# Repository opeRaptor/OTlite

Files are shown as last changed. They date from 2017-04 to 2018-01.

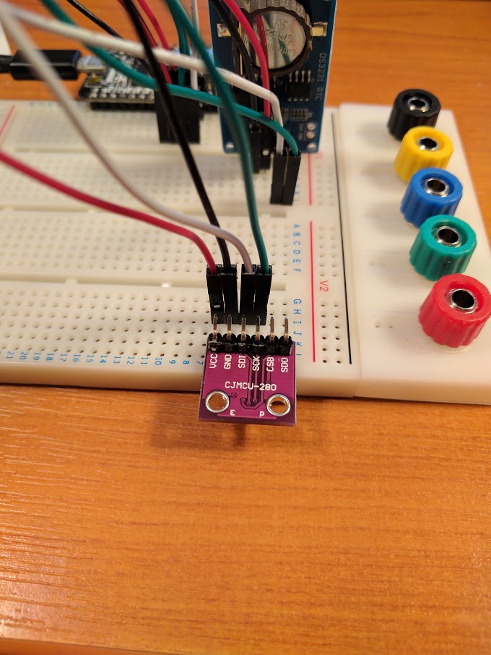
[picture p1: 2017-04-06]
Software/IMG_20170405_214116.jpg

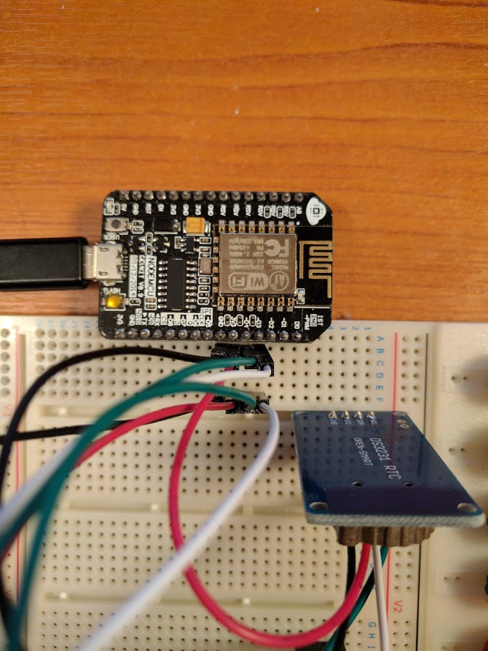
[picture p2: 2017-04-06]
Software/IMG_20170405_214140.jpg

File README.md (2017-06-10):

Obsolete Time Lite or O;TL for short, is the natural evolution of a previous project aiming to design the perfect desktop Nixie clock. 

 -Minimal design
 
 -Small form factor 
 
 -WiFi capable 
 
 -USB power 
 
 -Various atmospheric sensors. 

Reach out on Twitter: 
@SuprNova

Follow development on HackaDay.io:
https://hackaday.io/project/20439-obsolete-time-lite-a-minty-nixie-clock

OTL

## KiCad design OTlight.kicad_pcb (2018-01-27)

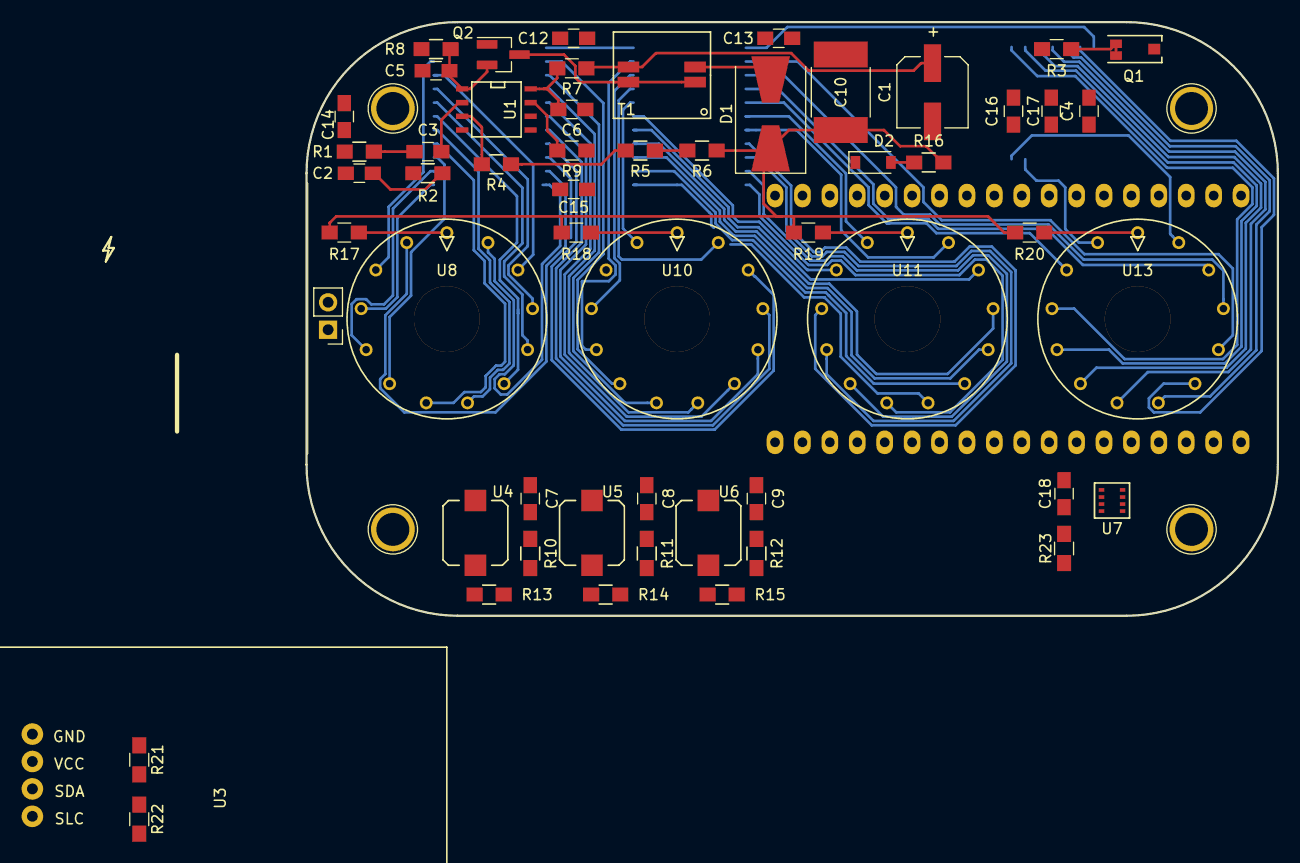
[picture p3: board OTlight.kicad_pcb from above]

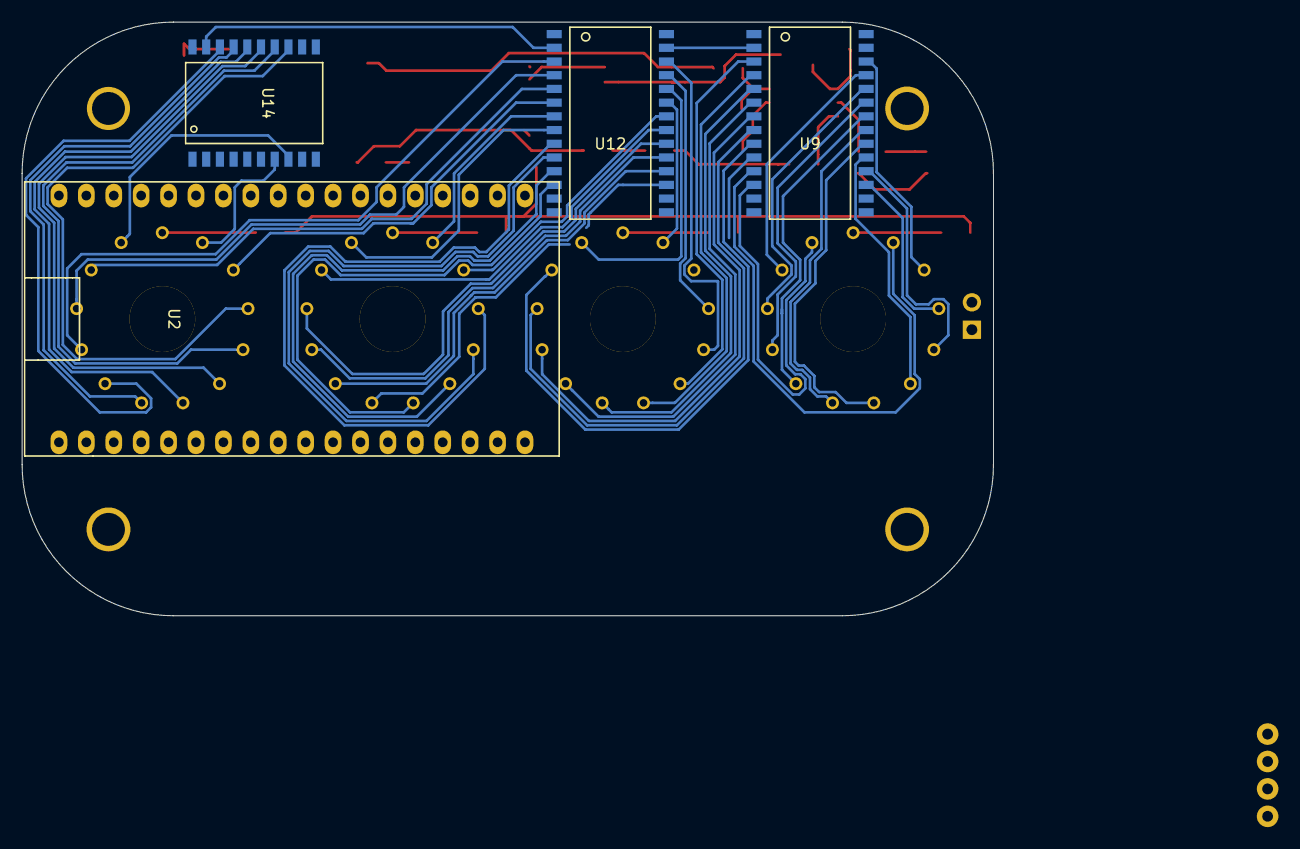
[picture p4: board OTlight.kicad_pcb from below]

Board: 2 copper layers, 90.0 x 55.0 mm, 60 parts (4 on the bottom side), 82 nets.

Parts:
C1: 220u; CP_Elec_6.3x7.7
C2: 0.001; C_0805_HandSoldering
C3, C6, C7, C8, C9, C18: 0.1u; C_0805_HandSoldering
C4: 10u; C_0805_HandSoldering
C5: 0.01u; C_0805_HandSoldering
C10: 1u; C_2220_HandSoldering
C12, C13, C14, C15, C16, C17: C_Small; C_0805_HandSoldering
D1: STPS4S200; D_SMB-SMC_Universal_Handsoldering
D2: D_Zener_Small_ALT; D_SOD-123
P1: CONN_01X02; Pin_Header_Straight_1x02_Pitch2.54mm
Q1: TEMT6000
Q2: RSR030N06TL; SOT-23_Handsoldering
R1: 1K; R_0805_HandSoldering
R2: 13K; R_0805_HandSoldering
R3, R10, R11, R12, R13, R14, R15, R16, R17, R18, R19, R20, R21, R22, R23: R_Small; R_0805_HandSoldering
R4: 1M; R_0805_HandSoldering
R5: 820K; R_0805_HandSoldering
R6: 24K; R_0805_HandSoldering
R7: 20; R_0805_HandSoldering
R8: 0.1; R_0805_HandSoldering
R9: 15K; R_0805_HandSoldering
T1: TRANSFO; CTX02-18714-R
U1: LM3478; SOIC-8-N
U2: ESP32; ESP32-OLED
U3: DS3231
U4, U5, U6: PushButton; SPEH120100
U7: bareBME280; BME280bare
U8, U10, U11, U13: IN-14; bearing-7mm
U9, U12: MAX6931; SW-28
U14: MAX6920; SW-20

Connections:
+3V3: C14.1, C15.1, C16.1, C18.2, Q1.1, R21.1, R22.1, R23.2, U3.2, U4.2, U5.2, U6.2, U7.2, U7.6, U7.8, U9.28, U12.28, U14.20
+5V: C1.1, C4.1, R7.1, T1.3
/CLK: U9.15, U12.15, U14.11
/HVout: C10.1, D1.1, P1.1, R6.1, R16.1, R17.1, R18.1, R19.1, R20.1
/LOAD: U9.16, U12.16, U14.12
GND: C1.2, C2.2, C4.2, C5.2, C6.2, C7.2, C8.2, C9.2, C10.2, C12.1, C13.1, C14.2, C15.2, C16.2, C17.1, C18.1, D2.1, P1.2, R1.2, R2.2, R3.2, R8.2, R9.1, R13.2, R14.2, R15.2, U1.4, U1.5, U3.1, U7.1, U7.7, U9.13, U9.14, U12.13, U12.14, U14.9, U14.10
unnamed: C2.1, R2.1, R4.2, U1.3
unnamed: C3.1, U1.2
unnamed: C3.2, R1.1
unnamed: C5.1, Q2.2, R8.1, U1.1
unnamed: C6.1, R7.2, U1.8
unnamed: C7.1, R10.1
unnamed: C8.1, R11.1
unnamed: C9.1, R12.1
unnamed: C12.2, C13.2, C17.2, D2.2, R16.2, U9.1, U12.1, U14.1
unnamed: D1.2, T1.2
unnamed: Q1.2, R3.1
unnamed: Q2.1, U1.6
unnamed: Q2.3, T1.1, T1.4
unnamed: R4.1, R5.2
unnamed: R5.1, R6.2
unnamed: R9.2, U1.7
unnamed: R10.2, R13.1, U4.1
unnamed: R11.2, R14.1, U5.1
unnamed: R12.2, R15.1, U6.1
unnamed: R17.2, U8.1
unnamed: R18.2, U10.1
unnamed: R19.2, U11.1
unnamed: R20.2, U13.1
unnamed: R21.2, U3.3, U7.3
unnamed: R22.2, U3.4, U7.4
unnamed: R23.1, U7.5
unnamed: U8.2, U9.12
unnamed: U8.3, U9.25
unnamed: U8.4, U9.24
unnamed: U8.5, U9.23
unnamed: U8.6, U9.22
unnamed: U8.7, U9.21
unnamed: U8.8, U9.20
unnamed: U8.9, U9.19
unnamed: U8.10, U9.18
unnamed: U8.11, U9.17
unnamed: U8.12, U9.26
unnamed: U8.13, U9.11
unnamed: U10.2, U12.24
unnamed: U9.9, U10.3
unnamed: U9.8, U10.4
unnamed: U9.7, U10.5
unnamed: U9.6, U10.6
unnamed: U9.5, U10.7
unnamed: U9.4, U10.8
unnamed: U9.3, U10.9
unnamed: U10.10, U12.26
unnamed: U10.11, U12.25
unnamed: U9.10, U10.12
unnamed: U10.13, U12.23
unnamed: U11.2, U12.8
unnamed: U11.3, U12.21
unnamed: U11.4, U12.20
unnamed: U11.5, U12.19
unnamed: U11.6, U12.18
unnamed: U11.7, U12.17
unnamed: U11.8, U12.12
unnamed: U11.9, U12.11
unnamed: U11.10, U12.10
unnamed: U11.11, U12.9
unnamed: U11.12, U12.22
unnamed: U11.13, U12.7
unnamed: U12.2, U14.19
unnamed: U12.3, U13.5
unnamed: U12.4, U13.4
unnamed: U12.5, U13.3
unnamed: U12.6, U13.12
unnamed: U9.2, U12.27
unnamed: U13.2, U14.8
unnamed: U13.6, U14.18
unnamed: U13.7, U14.17
unnamed: U13.8, U14.16
unnamed: U13.9, U14.15
unnamed: U13.10, U14.14
unnamed: U13.11, U14.13
unnamed: U13.13, U14.7

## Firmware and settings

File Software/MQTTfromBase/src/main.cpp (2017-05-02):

#include "Arduino.h"
#include <ESP8266WiFi.h>
#include <Wire.h>
#include <SPI.h>
#include "RTClib.h"
#include <PubSubClient.h>
#include <WiFiUdp.h>

RTC_DS3231 rtc;
char daysOfTheWeek[7][12] = {"Sunday", "Monday", "Tuesday", "Wednesday", "Thursday", "Friday", "Saturday"};

#define BME_SCK 13
#define BME_MISO 12
#define BME_MOSI 11
#define BME_CS 10
#define left_Button 16
#define middle_Button 5
#define right_Button 4



void shift(int NixietodisplayUpdate [8]);
void shift(int NixietodisplayUpdate);
void displayUpdate (int duration);
void displayUpdate (void);
void displayUpdate (int numbers,int duration);
void GetTime();
void GetDate();

void callback(char* topic, byte* payload, unsigned int length);
void reconnect();

bool adjust(void); //NTP time adjust
void sendNTPpacket(IPAddress *address);

unsigned long delayTime;

//=======================================INCLUDE==NTP======================================
/// NTP Server address
const char* ntpServerName = "0.uk.pool.ntp.org";
const double timezone = 1.0;
// local port to listen for UDP packets
const unsigned int localPort = 2390;
/// A UDP instance to let us send and receive packets over UDP
WiFiUDP udp;

/// Weekday strings.
//char daysOfTheWeek[][4] = {"Sun", "Mon", "Tue", "Wed", "Thu", "Fri", "Sat"};
/**
 * @brief NTP Server IP variable.
 *
 * Don't hardwire the IP address or we won't get the benefits of the pool.
 */
IPAddress timeServerIP;
/// NTP time stamp is in the first 48 bytes of the message
const int NTP_PACKET_SIZE = 48;
/// buffer to hold incoming and outgoing packets
byte packetBuffer[ NTP_PACKET_SIZE];
//===================================================================================

int NixieArray [8];
int PreviousArray [8];
int Brightness = 10;
int transition = 16;

int clockPin = 13;
int BL = 15;
int dataPin = 14;
int latch = 12;


const char* mqtt_server = "iot.eclipse.org";
WiFiClient espClient;
PubSubClient client(espClient);
long lastMsg = 0;
char msg[50];
int value = 0;

void setup() {

  Serial.begin(9600);
  Wire.pins(0, 2); //SDA and SCL

  //MQTT setup
  client.setServer(mqtt_server, 1883);
  client.setCallback(callback);

  if (! rtc.begin()) {
    Serial.println("Couldn't find RTC");
    while (1);
  }

  if (rtc.lostPower()) {
    Serial.println("RTC lost power, lets set the time!");
    rtc.adjust(DateTime(F(__DATE__), F(__TIME__)));
  }

  // Start UDP Server to receive the NTP response.
  Serial.println("Starting UDP");
  udp.begin(localPort);
  Serial.println("Initial RTC sync with NTP");
  while (!adjust()){
    adjust();
  }

  pinMode(clockPin, OUTPUT);
  pinMode(BL, OUTPUT);
  pinMode(dataPin, OUTPUT);
  pinMode(latch, OUTPUT);

  pinMode(16, INPUT); // Left button
  pinMode(5, INPUT);  // Middle button
  pinMode(4, INPUT);  // Right button

  digitalWrite(BL, LOW);
  digitalWrite(latch, HIGH);

  digitalWrite(dataPin, HIGH);
  for (int i = 0; i < 50; i++)
  {
    digitalWrite(clockPin, HIGH);
    digitalWrite(clockPin, LOW);
  }

  if (!client.connected()) {
    reconnect();
  }

}


void loop()
{
  GetTime();
  displayUpdate();

  client.loop();

  DateTime now = rtc.now();
  int nowish = now.minute() / 10;

  if (nowish != lastMsg) {
    lastMsg = now.minute() / 10;
    ++value;
    snprintf (msg, 75, "x10min: %ld", value);
    //Serial.print("Publish message: ");
    //Serial.println(msg);
    client.publish("/OTL/batt", msg);
  }

  /*if (digitalRead(left_Button) == 1)
  {
    //see bottom of program for draft of chrono
  }

  if (digitalRead(middle_Button) == 1)
  {
    GetDate();
    displayUpdate (14);
    while (digitalRead(middle_Button) == 1)
    {
      displayUpdate(14);
    }
    GetTime();
    displayUpdate (14);
  }
  if (digitalRead(right_Button) == 1)
  {

    displayUpdate (14);
    while (digitalRead(middle_Button) == 1)
    {
      displayUpdate(14);
    }
    GetTime();
    displayUpdate (14);
  }*/
}

//=======================================FUNCTION==DISPLAYUPDATE================================
// Do a smooth transition between the previous array dipslayed and NiexieArray, for a given duration
void displayUpdate (int duration)
{
  int dots [8] = {10, 10, 10, 10, 0, 0, 0, 0};
  for (int i = 0; i < 4; ++i)
  {
    if ((PreviousArray [i]) != (NixieArray [i])) goto Change;
  }
  dots [4] = NixieArray [4];
  dots [5] = NixieArray [5];
  dots [6] = NixieArray [6];
  dots [7] = NixieArray [7];

  shift (NixieArray);
  delayMicroseconds (Brightness * 300);

  shift (dots);
  delayMicroseconds (Brightness * 50);

  if (Brightness != 10)
  {
    shift (10000);
    delayMicroseconds (3000 - Brightness * 300);
  }

  for (int i = 0; i < 8; ++i)
  {
    PreviousArray [i] = NixieArray [i];
  }
  return;

Change:
  dots [4] = NixieArray [4];
  dots [5] = NixieArray [5];
  dots [6] = NixieArray [6];
  dots [7] = NixieArray [7];

  int dots2 [8] = {10, 10, 10, 10, 0, 0, 0, 0};
  dots2 [4] = PreviousArray [4];
  dots2 [5] = PreviousArray [5];
  dots2 [6] = PreviousArray [6];
  dots2 [7] = PreviousArray [7];

  for (int i = 0; i < duration; i++)
  {
    shift (PreviousArray);
    delayMicroseconds ((duration - i) * 1000 * Brightness / 10);
    shift (dots2);
    delayMicroseconds ((duration - i) * 1000 * Brightness / 60);
    if (Brightness != 10)
    {
    shift (10000);
    delayMicroseconds ((duration - i) * 1000 * (10 - Brightness) / 10);
    }

    shift (NixieArray);
    delayMicroseconds (i * 1000 * Brightness / 10);
    shift (dots);
    delayMicroseconds (i * 1000 * Brightness / 60);
    if (Brightness != 10)
    {
    shift (10000);
    delayMicroseconds (i * 1000 * (10 - Brightness) / 10);
    }
  }
  for (int i = 0; i < 8; ++i)
  {
    PreviousArray [i] = NixieArray [i];
  }
}

void displayUpdate (void)
{
  displayUpdate(transition);
}

void displayUpdate (int numbers, int duration)
{
  NixieArray [0] = numbers / 1000;
  NixieArray [1] = (numbers / 100) % 10;
  NixieArray [2] = (numbers / 10) % 10;
  NixieArray [3] = numbers % 10;
  displayUpdate (duration);
}

//=======================================FUNCTION==SHIFT==============================
// displayUpdate numbers and dots, from an int array, left to right, 4 first are numbers, 4 last are dots
// If a number is not in the range 0-9, no numbers are lit up
// Dots: 0 is nothing, 1 is left dot, 2 is right dot, 3 is both dots
void shift(int NixietodisplayUpdate [8])
{
  int Nixiearray [10] = {8, 9, 0, 1, 2, 3, 4, 5, 6, 7};
  int j;

  for (int k = 3; k >= 0; k--)
  {
    digitalWrite(latch, LOW);
    digitalWrite(dataPin, HIGH);

    if ((NixietodisplayUpdate [k + 4] == 3) || (NixietodisplayUpdate [k + 4] == 1))   digitalWrite(dataPin, LOW);
    digitalWrite(clockPin, HIGH);
    digitalWrite(clockPin, LOW);
    digitalWrite(dataPin, HIGH);

    if ((NixietodisplayUpdate [k + 4] == 3) || (NixietodisplayUpdate [k + 4] == 2))   digitalWrite(dataPin, LOW);
    digitalWrite(clockPin, HIGH);
    digitalWrite(clockPin, LOW);
    digitalWrite(dataPin, HIGH);

    if ((NixietodisplayUpdate [k] > 9) || (NixietodisplayUpdate [k] < 0))
    {
      for (int i = 0; i < 10; i++)
      {
        digitalWrite(clockPin, HIGH);
        digitalWrite(clockPin, LOW);
      }
    }
    else
    {
      j = Nixiearray [NixietodisplayUpdate [k]];
      for (int i = 0; i < j; i++)
      {
        digitalWrite(clockPin, HIGH);
        digitalWrite(clockPin, LOW);
      }
      digitalWrite(dataPin, LOW);
      digitalWrite(clockPin, HIGH);
      digitalWrite(clockPin, LOW);
      digitalWrite(dataPin, HIGH);
      for (int i = 0; i < (9 - j); i++)
      {
        digitalWrite(clockPin, HIGH);
        digitalWrite(clockPin, LOW);
      }
    }
    digitalWrite(latch, HIGH);
  }
}

void shift(int NixietodisplayUpdate)
{
  int nixiebuffer [8];
  if (NixietodisplayUpdate == 10000)
  {
    nixiebuffer [0] = 10;
    nixiebuffer [1] = 10;
    nixiebuffer [2] = 10;
    nixiebuffer [3] = 10;
  }
  else
  {
    nixiebuffer [0] = NixietodisplayUpdate / 1000;
    nixiebuffer [1] = (NixietodisplayUpdate / 100) % 10;
    nixiebuffer [2] = (NixietodisplayUpdate / 10) % 10;
    nixiebuffer [3] = NixietodisplayUpdate % 10;
  }
  nixiebuffer [4] = 0;
  nixiebuffer [5] = 0;
  nixiebuffer [6] = 0;
  nixiebuffer [7] = 0;
  if (NixietodisplayUpdate == 10000)
  {
    nixiebuffer [0] = 10;
    nixiebuffer [1] = 10;
    nixiebuffer [2] = 10;
    nixiebuffer [3] = 10;
  }

  shift(nixiebuffer);
}

//=======================================FUNCTION==GETTIME================================
void GetTime()
{
  DateTime now = rtc.now();

  NixieArray [0] = now.hour() / 10;
  NixieArray [1] = now.hour() % 10;
  NixieArray [2] = now.minute() / 10;
  NixieArray [3] = now.minute() % 10;
  NixieArray [4] = 0;
  NixieArray [5] = 0;
  NixieArray [6] = 0;
  NixieArray [7] = 0;

  if ((now.second() % 2) == 1) NixieArray [5] = 2;
  else NixieArray [6] = 1;
}


//=======================================FUNCTION==GETDATE================================
void GetDate()
{
  DateTime now = rtc.now();

  NixieArray [0] = now.month() / 10;
  NixieArray [1] = now.month() % 10;
  NixieArray [2] = now.day() / 10;
  NixieArray [3] = now.day() % 10;
  NixieArray [4] = 0;
  NixieArray [5] = 2;
  NixieArray [6] = 0;
  NixieArray [7] = 0;
}

//=======================================FUNCTION==SERIAL==RTC============================
void printRTCValues() {
  DateTime now = rtc.now();

  Serial.print(now.year(), DEC);
  Serial.print('/');
  Serial.print(now.month(), DEC);
  Serial.print('/');
  Serial.print(now.day(), DEC);
  Serial.print(" (");
  Serial.print(daysOfTheWeek[now.dayOfTheWeek()]);
  Serial.print(") ");
  Serial.print(now.hour(), DEC);
  Serial.print(':');
  Serial.print(now.minute(), DEC);
  Serial.print(':');
  Serial.print(now.second(), DEC);
  Serial.println();

  Serial.println();
  delay(delayTime);
}
//=======================================FUNCTION==MQTTCallback============================
void callback(char* topic, byte* payload, unsigned int length) {
  Serial.print("Message arrived [");
  Serial.print(topic);
  Serial.print("] ");
  for (int i = 0; i < length; i++) {
    Serial.print((char)payload[i]);
  }
  Serial.println();
}
//=======================================FUNCTION==MQTTreconnect============================
void reconnect() {
  // Loop until we're reconnected
  while (!client.connected()) {
    Serial.print("Attempting MQTT connection...");
    // Create a random client ID
    String clientId = "ESP8266Client-";
    clientId += String(random(0xffff), HEX);
    // Attempt to connect
    if (client.connect(clientId.c_str())) {
      Serial.println("connected");
      // Once connected, publish an announcement...
      client.publish("/OTL/batt", "beginBatt test");
      // ... and resubscribe
      client.subscribe("/OTL/incoming");
    } else {
      Serial.print("failed, rc=");
      Serial.print(client.state());
      Serial.println(" try again in 5 seconds");
      // Wait 5 seconds before retrying
      delay(5000);
    }
  }
}
//=======================================NTP==FUNCTION============================================
/**
 * @brief Adjust the DS3231 with current date and time.
 *
 * <pre>
 * NTPv4 Basic Header Specification:
 *
 * Bytes  : Description
 * -------:----------------------
 *       0: LI(2), VN(3), Mode(3)
 *       1: Stratum
 *       2: Poll
 *       3: Precision
 *  4 -  7: Root Delay
 *  8 - 11: Root Dispersion
 * 12 - 15: Reference ID
 * 16 - 23: Reference Timestamp
 * 24 - 31: Origin Timestamp
 * 32 - 39: Receive Timestamp
 * 40 - 47: Transmit Timestamp
 *
 * Transmit Timestamp:
 * Time at the server when the response left for the client, in NTP timestamp format.
 *
 *
 * NTP timestamp format
 *
 * Bytes: Description
 * -----:-------------------
 * 0 - 3: Seconds since 1900
 * 4 - 7: Fraction of Second
 * </pre>
 *
 */
bool adjust(void)
{
  unsigned long mi;
  int cb = 0;

  //get a random server from the pool
  WiFi.hostByName(ntpServerName, timeServerIP);

  // send an NTP packet to a time server
  sendNTPpacket(&timeServerIP);
  mi = millis();

  // wait to see if a reply is available
  while (millis() - mi < 2000 && !cb)
  {
    cb = udp.parsePacket();
    yield();
  }

  if (!cb)
  {
    Serial.println("[ERROR]: No packet available.");

    return 0;
  }

  //Serial.print("packet received, length=");
  //Serial.println(cb);
  // We've received a packet, read the data from it
  udp.read(packetBuffer, NTP_PACKET_SIZE); // read the packet into the buffer

  //the timestamp starts at byte 40 of the received packet and is four bytes,
  // or two words, long. First, esxtract the two words:

  unsigned long highWord = word(packetBuffer[40], packetBuffer[41]);
  unsigned long lowWord = word(packetBuffer[42], packetBuffer[43]);
  // combine the four bytes (two words) into a long integer
  // this is NTP time (seconds since Jan 1 1900):
  unsigned long secsSince1900 = highWord << 16 | lowWord;
  //Serial.print("Seconds since Jan 1 1900 = " );
  //Serial.println(secsSince1900);

  // now convert NTP time into everyday time:
  Serial.print("Unix UTC time = ");
  // Unix time starts on Jan 1 1970. In seconds, that's 2208988800:
  const unsigned long seventyYears = 2208988800UL;
  // subtract seventy years:
  unsigned long epoch = secsSince1900 - seventyYears;
  // print Unix time:
  Serial.println(epoch);

  // adjust to user timezone
  epoch += timezone * 3600;

  //rtc.setEpoch(epoch);
  rtc.adjust(epoch); //adjust RTC time to NTP time
  return 1;
}

void sendNTPpacket(IPAddress *address)
{
  Serial.println("sending NTP packet...");

  // set all bytes in the buffer to 0
  memset(packetBuffer, 0, NTP_PACKET_SIZE);

  // Initialize values needed to form NTP request
  // (see URL above for details on the packets)
  packetBuffer[0] = 0b11100011;   // LI, Version, Mode
  packetBuffer[1] = 0;     // Stratum, or type of clock
  packetBuffer[2] = 6;     // Polling Interval
  packetBuffer[3] = 0xEC;  // Peer Clock Precision
  // 8 bytes of zero for Root Delay & Root Dispersion
  packetBuffer[12]  = 49;
  packetBuffer[13]  = 0x4E;
  packetBuffer[14]  = 49;
  packetBuffer[15]  = 52;

  // all NTP fields have been given values, now
  // you can send a packet requesting a timestamp:
  udp.beginPacket(*address, 123); //NTP requests are to port 123
  udp.write(packetBuffer, NTP_PACKET_SIZE);
  udp.endPacket();
}

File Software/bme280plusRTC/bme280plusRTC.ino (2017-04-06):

/***************************************************************************
  This is a library for the BME280 humidity, temperature & pressure sensor

  Designed specifically to work with the Adafruit BME280 Breakout
  ----> http://www.adafruit.com/products/2650

  These sensors use I2C or SPI to communicate, 2 or 4 pins are required
  to interface. The device's I2C address is either 0x76 or 0x77.

  Adafruit invests time and resources providing this open source code,
  please support Adafruit andopen-source hardware by purchasing products
  from Adafruit!

  Written by Limor Fried & Kevin Townsend for Adafruit Industries.
  BSD license, all text above must be included in any redistribution
 ***************************************************************************/

#include <Wire.h>
#include <SPI.h>
#include <Adafruit_Sensor.h>
#include <Adafruit_BME280.h>
#include "RTClib.h"

RTC_DS3231 rtc;
char daysOfTheWeek[7][12] = {"Sunday", "Monday", "Tuesday", "Wednesday", "Thursday", "Friday", "Saturday"};

#define BME_SCK 13
#define BME_MISO 12
#define BME_MOSI 11
#define BME_CS 10

#define SEALEVELPRESSURE_HPA (1013.25)

Adafruit_BME280 bme; // I2C
//Adafruit_BME280 bme(BME_CS); // hardware SPI
//Adafruit_BME280 bme(BME_CS, BME_MOSI, BME_MISO, BME_SCK); // software SPI

unsigned long delayTime;

void setup() {
    
    Serial.begin(9600);
    Wire.pins(0,2); //SDA and SCL
    Serial.println(F("BME280 test"));

    if (! rtc.begin()) {
    Serial.println("Couldn't find RTC");
    while (1);
  }

  if (rtc.lostPower()) {
    Serial.println("RTC lost power, lets set the time!");
    // following line sets the RTC to the date & time this sketch was compiled
    rtc.adjust(DateTime(F(__DATE__), F(__TIME__)));
    // This line sets the RTC with an explicit date & time, for example to set
    // January 21, 2014 at 3am you would call:
    // rtc.adjust(DateTime(2014, 1, 21, 3, 0, 0));
  }


    bool status;
    
    // default settings
    status = bme.begin();
    if (!status) {
        Serial.println("Could not find a valid BME280 sensor, check wiring!");
        while (1);
    }
    
    Serial.println("-- Default Test --");
    delayTime = 1000;

    Serial.println();
}


void loop() { 
    printValues();

    DateTime now = rtc.now();
    
    Serial.print(now.year(), DEC);
    Serial.print('/');
    Serial.print(now.month(), DEC);
    Serial.print('/');
    Serial.print(now.day(), DEC);
    Serial.print(" (");
    Serial.print(daysOfTheWeek[now.dayOfTheWeek()]);
    Serial.print(") ");
    Serial.print(now.hour(), DEC);
    Serial.print(':');
    Serial.print(now.minute(), DEC);
    Serial.print(':');
    Serial.print(now.second(), DEC);
    Serial.println();
    
    Serial.println();
    delay(delayTime);
}


void printValues() {
    Serial.print("Temperature = ");
    Serial.print(bme.readTemperature());
    Serial.println(" *C");

    Serial.print("Pressure = ");

    Serial.print(bme.readPressure() / 100.0F);
    Serial.println(" hPa");

    Serial.print("Approx. Altitude = ");
    Serial.print(bme.readAltitude(SEALEVELPRESSURE_HPA));
    Serial.println(" m");

    Serial.print("Humidity = ");
    Serial.print(bme.readHumidity());
    Serial.println(" %");

    Serial.println();
}

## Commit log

2017-01-18 Initial Push~
    [OTlight.sch]
2017-01-20 Everything Connected
    [OTlight.sch]
2017-01-21 Touch up + added I2C Pullups
    [OTlight.sch, noname.kicad_pcb]
2017-01-21 Schematic Update
    changelog:
    - Linked labels
    - Added MAXIM6920 to rout the dot
    - Set values to passive components
    - Cosmetic changes
    [OTlight.sch]
2017-01-22 Fixes + PCB created
    Fixed buttons generated PCB+ started rough laying
    [OTlight.kicad_pcb, OTlight.sch]
2017-03-08 Components fitted
    Everything fits!
    [OTlight.kicad_pcb, OTlight.sch, noname.kicad_pcb]
2017-03-09 PSU on board organised
    [OTlight.kicad_pcb]
2017-03-12 ShiftRegisters + Nixies Routed
    ESP in place also
    [OTlight.kicad_pcb]
2017-03-15 PSU rooted
    Needs clean up and RTC+Barometer fitted
    [OTlight.kicad_pcb]
2017-03-16 Finished routing PCB
    [OTlight.kicad_pcb]
2017-03-18 Clean up
    We are getting there!
    [OTlight.kicad_pcb]
2017-03-22 Biribiri silkscreen, clean up, where are the GND vias?
    [OTlight.kicad_pcb]
2017-03-25 Separated all the pads from the vias... sigh
    [OTlight.kicad_pcb]
2017-03-25 Misakaimouto Silk + miniBiri stitch
    [OTlight.kicad_pcb]
2017-03-25 Added Edgecut on top of the Altoids silkscreen
    [OTlight.kicad_pcb]
2017-03-25 Board size to fit Altoids+ decoupling caps
    NOTHING IS WHERE IT SHOULD BE
    EVERYTHING IS WRONG
    I AM GOING TO BED!
    [OTlight.kicad_pcb, OTlight.sch]
2017-03-25 Errr... as below but this time I saved first.
    [OTlight.kicad_pcb]
2017-03-26 Updated PCB and footprints - Changed footprints for angled pins SMD package - Repositioned holes - Locked Altoids shaped outline, holes, tubes and modules - Changed R3 for resistor package (was 0805 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
    [OTlight.kicad_pcb, OTlight.sch]
2017-03-26 Updated footprints meant reroute No unconnected traces, silk adjusted.
    [OTlight.kicad_pcb]
2017-04-05 Software Test of RTC + ATH Wire.pins(0,2); //SDA and SCL
2017-04-05 Renamed components on schematics for more sensible name Also changed diode orientation and BME280 pinout
    [OTlight.sch]
2017-04-06 I2C footprint, silk and diode adjustments
    [OTlight.kicad_pcb, OTlight.sch]
2017-04-06 Final silk adjustment. Ready for fab?
    [OTlight.kicad_pcb]
2017-04-14 Changed QR code for non inverted colours Moved Q2 silkscreen Changed Biri-Biri via for 0.3mm
    [OTlight.kicad_pcb]
2017-04-17 Software started - all modules tested Test 1 just test the tubes Test 2 is a draft of all modules somehow working + some features
2017-04-19 Reverted changes to test 2
    [OT_L_provisional_test_2.ino]
2017-04-19 Reverted Test 2... This time I mean it.
    [OT_L_provisional_test_2.ino]
2017-04-23 Final cleanup of most basic functions Chronometer commented out Some glitches are remaining for the Transition function
    [OT_L_provisional_test_2.1.ino]
2017-04-23 Updated tube brightness control
2017-05-02 Updates MQTT every 10min for battery test.
2017-05-15 Rev2 of the board Everything fits and is connected~
    [OTlight.kicad_pcb, OTlight.sch]
2017-05-18 Cleanup started
    [OTlight.sch]
2017-05-19 Added edge cut and M3 mounting holes
    [OTlight.kicad_pcb]
2018-01-20 The start of bearing upgrade
    [OTlight.kicad_pcb, _saved_OTlight.sch]
2018-01-20 Realigned tubes with bearings, now the tubes are perfectly centered on both x and y axis
    [OTlight.kicad_pcb, _saved_OTlight.sch]
2018-01-27 Everything in place with bearings sockets.
    [OTlight-2018-01-21-22-49-41.sch, OTlight.kicad_pcb]
2018-02-22 Add files via upload
    Added Test nixie bearing files, just a quick PCB for testing various settings on the tube sockets with bearings.
    Note the associated footprints are not in Bamboulib, since I had to create about 20 abominations to create this monstruosity, if the tests are successful I will upload the appropriate libraries
    [Test nixie bearing-B.Cu.gbr, Test nixie bearing-B.Mask.gbr, Test nixie bearing-B.SilkS.gbr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]
